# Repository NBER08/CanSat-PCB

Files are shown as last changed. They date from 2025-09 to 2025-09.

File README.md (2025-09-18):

# A custom PCB for the 2026 Hungarian CanSat competition
This is the the design me and my team are working on this year. This is the second year that we try ourselves at this competition. Dispite last years sub-optimal results we are determined to give our everything. Our goal this year is to get to the finals and launch our CanSat.

## General architecture

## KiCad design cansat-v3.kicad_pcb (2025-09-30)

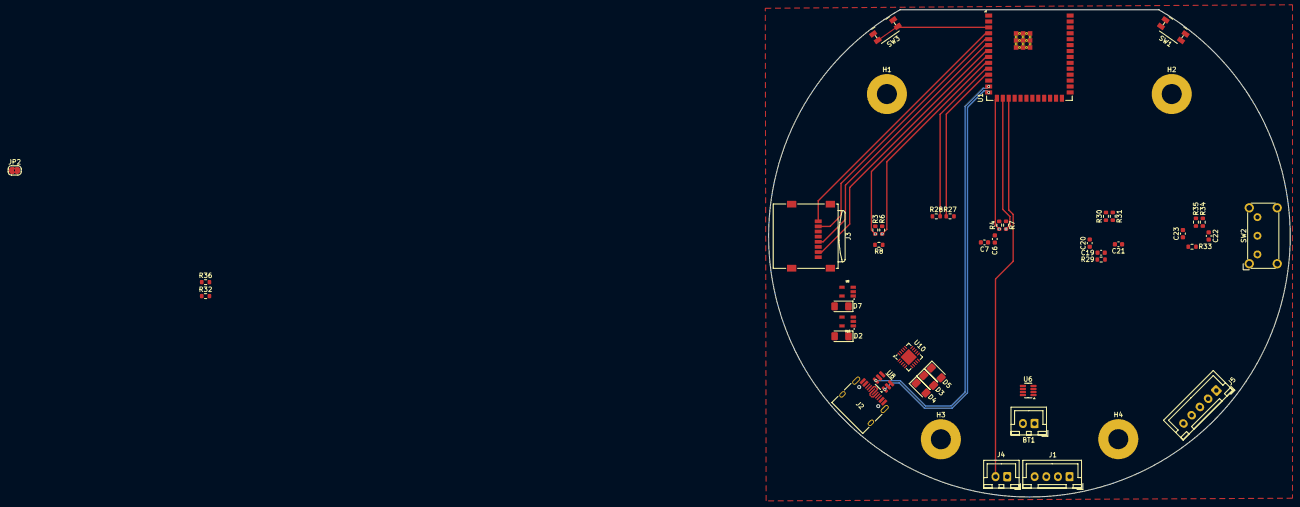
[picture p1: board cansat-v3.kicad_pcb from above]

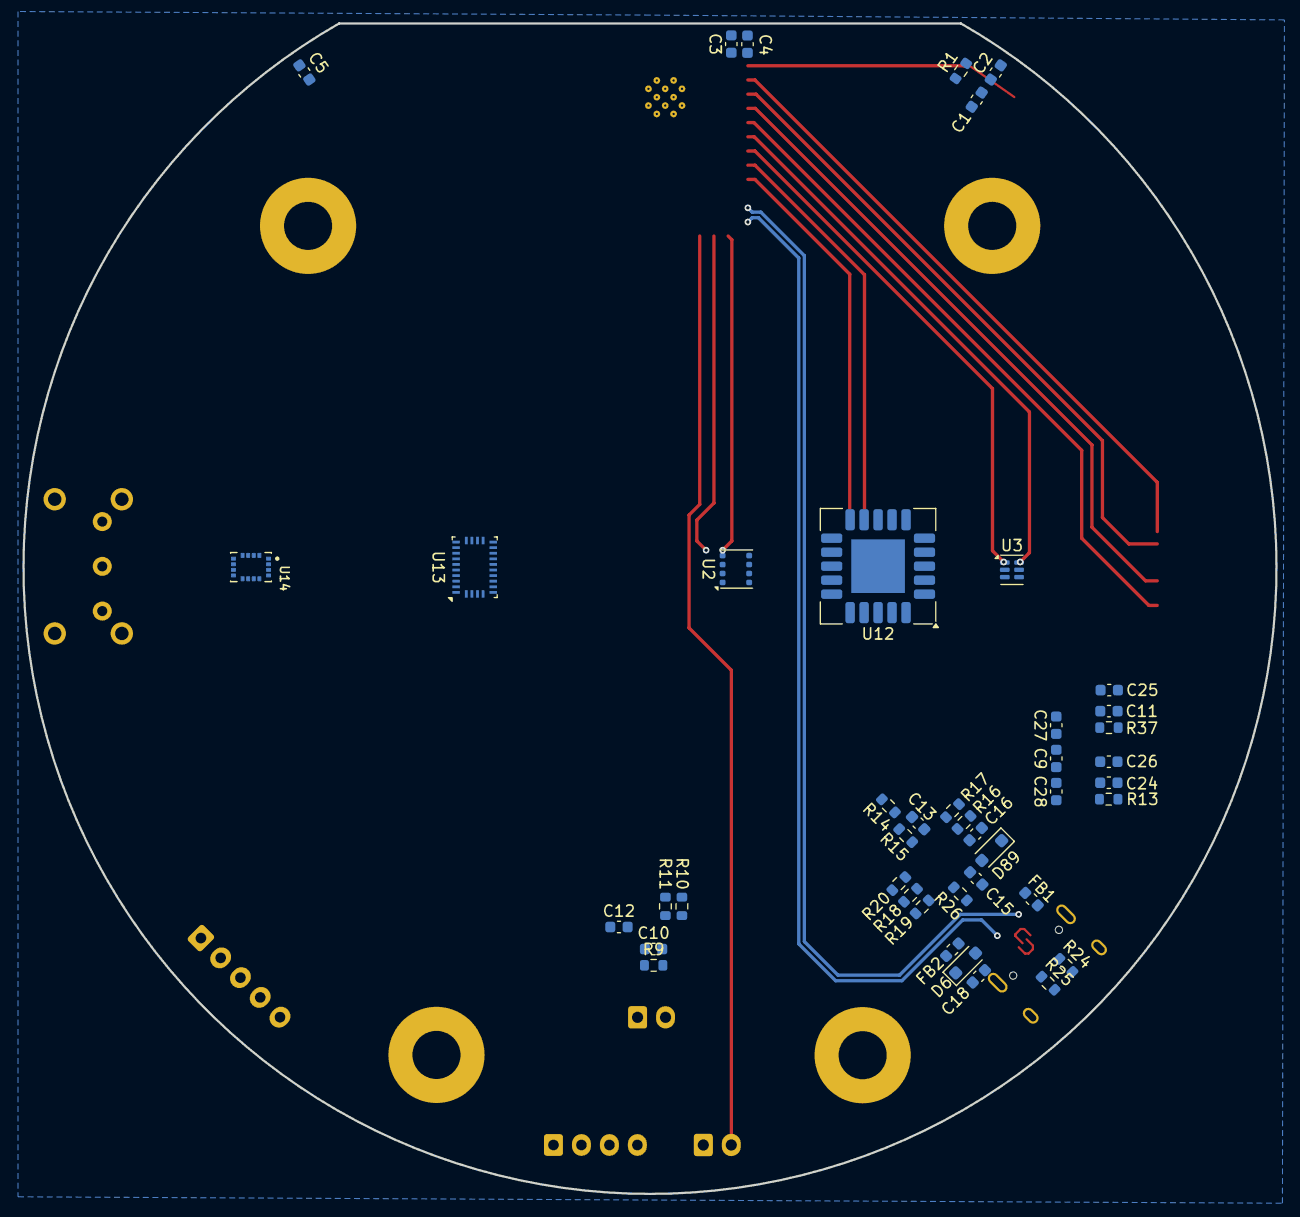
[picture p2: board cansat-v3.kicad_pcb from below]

Board: 4 copper layers, 112.0 x 104.6 mm, 90 parts (43 on the bottom side), 60 nets.

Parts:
BT1: Battery; JST_XH_B2B-XH-A_1x02_P2.50mm_Vertical
C1, C3, C5, C6, C7, C11, C12, C19, C22, C23, C24, C27, C28: 0.1u; C_0603_1608Metric
C2, C16: 10u; C_0603_1608Metric
C4: 22u; C_0603_1608Metric
C9: 470u; C_0603_1608Metric
C10, C20: 1u; C_0603_1608Metric
C13, C15: 4.7u; C_0603_1608Metric
C18: 100n; C_0603_1608Metric
C21: 0.12u; C_0603_1608Metric
C25, C26: 22n; C_0603_1608Metric
D2, D7: LED; LED_1206_3216Metric_Pad1.42x1.75mm_HandSolder
D3: Blue; LED_1206_3216Metric_Pad1.42x1.75mm_HandSolder
D4: Orange; LED_1206_3216Metric_Pad1.42x1.75mm_HandSolder
D5: Green; LED_1206_3216Metric_Pad1.42x1.75mm_HandSolder
D6: D_SOD-323_HandSoldering
D89: 1N5819; D_SOD-323_HandSoldering
FB1, FB2: LI0603G121R-10; L_0603_1608Metric
H1, H2, H3, H4: MountingHole_Pad; MountingHole_4.3mm_M4_Pad
J1: Conn_01x04_Socket; JST_XH_B4B-XH-A_1x04_P2.50mm_Vertical
J2: USB_C_Receptacle_USB2.0_16P; USB_C_Receptacle_HRO_TYPE-C-31-M-12
J3: Micro_SD_Card; microSD_HC_Wuerth_693072010801
J4: Conn_01x02_Socket; JST_XH_B2B-XH-A_1x02_P2.50mm_Vertical
J5: Conn_01x05_Socket; JST_XH_B5B-XH-A_1x05_P2.50mm_Vertical
JP2: SolderJumper_2_Bridged; SolderJumper-2_P1.3mm_Bridged2Bar_RoundedPad1.0x1.5mm
R1, R26, R27, R28, R29, R32, R36: 10k; R_0603_1608Metric
R3, R4, R6, R7, R8, R30, R31: 4.7k; R_0603_1608Metric
R9: 0.2; R_0603_1608Metric
R10, R11: 3.3k; R_0603_1608Metric
R13, R37: 66.5; R_0603_1608Metric
R14, R16: 2k; R_0603_1608Metric
R15: 1k; R_0603_1608Metric
R17: 2.4k; R_0603_1608Metric
R18: 68; R_0603_1608Metric
R19: 115; R_0603_1608Metric
R20: 100; R_0603_1608Metric
R24, R25: 5.1k; R_0603_1608Metric
R33: 3.3M; R_0603_1608Metric
R34, R35: 820; R_0603_1608Metric
SW1, SW3: SW_Push; Panasonic_EVQPUJ_EVQPUA
SW2: PWR; SW_E-Switch_EG1224_SPDT_Angled
U1: ESP32-S3-WROOM-2
U2: BME680; Bosch_LGA-8_3x3mm_P0.8mm_ClockwisePinNumbering
U3: TSL25911FN; AMS_TSL25911FN
U5: Analog PS; SOT94P279X129-5N
U6: INA219BxDCN; SOT-23-8
U8: SRV05-4; SOT-23-6_Handsoldering
U10: MCP73871; QFN-20-1EP_4x4mm_P0.5mm_EP2.5x2.5mm
U12: SCD40-D-R2; Sensirion_SCD4x-1EP_10.1x10.1mm_P1.25mm_EP4.8x4.8mm
U13: BNO055; LGA-28_5.2x3.8mm_P0.5mm
U14: AS7331-AQFM; PQFN50P365X260X119-16N
U15: Digital PS; SOT94P279X129-5N

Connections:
+3.3V: C3.1, C4.1, C6.1, C7.2, C12.2, C19.1, C22.1, C24.2, J1.1, J3.4 (VDD), J5.1, R1.1, R3.1, R4.2, R6.1, R7.2, R8.1, R10.1, R11.1, R13.1, R16.1, R27.1, R28.1, R29.1, R30.2, R31.2, R34.2, R35.2, U1.2 (3V3), U2.2 (CSB), U2.6 (VDDIO), U2.8 (VDD), U3.5 (VDD), U6.4 (VS), U10.4 (PROG2), U12.7 (VDD), U12.19 (VDD), U13.3 (VDD), U14.10 (VDDD), U15.5 (VOUT)
+5V: C16.1, D3.2 (A), D4.2 (A), D5.2 (A), FB1.2, U8.5 (VP), U10.2 (VPCC), U10.18 (IN), U10.19 (IN)
+BATT: BT1.1 (+), C10.1, C13.1, R9.1, SW2.1 (A), U6.1 (IN+), U10.14 (V_{BAT}), U10.15 (V_{BAT}), U10.16 (V_{BAT_SENSE})
/RST: C1.2, C2.1, R1.2, SW3.2, U1.3 (EN)
AS7331_SCL: R35.1, U1.33 (MTDO/IO40), U14.13 (SCL)
AS7331_SDA: R34.1, U1.34 (MTDI/IO41), U14.12 (SDA)
BME680_SCL: R4.1, U1.15 (IO3), U2.4 (SCK)
BME680_SDA: R7.1, U1.16 (IO46), U2.3 (SDI)
BNO055_RST: U1.23 (IO21), U13.11 (~RESET)
BNO055_SCL: R30.1, U1.31 (IO38), U13.19 (COM1)
BNO055_SDA: R31.1, U1.26 (IO45), U13.20 (COM0)
COMPASS_SCL: J4.2, U1.17 (IO9)
COMPASS_SDA: J4.1, U1.18 (IO10)
Earth: C18.1, D6.2 (A2), FB2.2, J2.A1 (GND), J2.A12 (GND), J2.B1 (GND), J2.B12 (GND), J2.S1 (SHIELD)
GND: BT1.2 (-), C1.1, C2.2, C3.2, C4.2, C5.1, C6.2, C7.1, C10.2, C11.1, C12.1, C13.2, C15.2, C16.2, C18.2, C19.2, C20.1, C21.1, C22.2, C24.1, C25.1, C26.1, C27.2, C28.1, D2.1 (K), D6.1 (A1), D7.1 (K), FB2.1, H1.1, H2.1, H3.1, H4.1, J1.2, J3.3 (CMD), J3.6 (VSS), J5.4, JP2.1 (A), R9.2, R14.2, R15.2, R17.2, R24.2, R25.2, R26.2, R32.2, R36.2, SW1.2, SW3.1, U1.1 (GND), U1.40 (GND), U1.41 (GND), U2.1 (GND), U2.5 (SDO), U2.7 (GND), U3.3 (GND), U5.2 (GND), U6.2 (IN-), U6.3 (GND), U6.7 (A0), U6.8 (A1), U8.2 (VN), U10.3 (SEL), U10.9 (~TE), U10.10 (V_{SS}), U10.11 (V_{SS}), U10.21 (V_{SS}), U12.6 (GND), U12.20 (GND), U12.21 (GND), U13.2 (GND), U13.5 (PS1), U13.6 (PS0), U13.17 (COM3), U13.18 (COM2), U13.25 (GNDIO), U14.11 (VSSD), U15.2 (GND)
GPS_RX: J1.3, U1.21 (IO13)
GPS_TX: J1.4, U1.22 (IO14)
INA219_SCL: R11.2, U1.20 (IO12), U6.5 (SCL)
INA219_SDA: R10.2, U1.19 (IO11), U6.6 (SDA)
LoRa_RST: J5.5, U1.32 (MTCK/IO39)
LoRa_RX: J5.3, U1.36 (RXD0/IO44)
LoRa_TX: J5.2, U1.37 (TXD0/IO43)
unnamed: D2.2 (A), R13.2
unnamed: D3.1 (K), R18.1
unnamed: D4.1 (K), R19.1
unnamed: D5.1 (K), R20.1
unnamed: D7.2 (A), R37.2
unnamed: C15.1, D89.2 (A), U10.1 (OUT), U10.20 (OUT)
unnamed: C9.1, C9.2, C27.1, C28.2, D89.1 (K), U5.1 (VIN), U15.1 (VIN)
unnamed: J2.A5 (CC1), R24.1
unnamed: J2.B5 (CC2), R25.1
unnamed: C5.2, SW1.1, U1.27 (IO0)
unnamed: R8.2, U3.2 (INT)
unnamed: C25.2, U5.4 (BP)
unnamed: R16.2, R17.1, U10.17 (CE)
unnamed: R14.1, U10.13 (PROG1)
unnamed: R15.1, U10.12 (PROG3)
unnamed: R20.2, U10.8 (STAT1/~LBO)
unnamed: R18.2, U10.7 (STAT2)
unnamed: R26.1, U10.5 (THERM)
unnamed: R19.2, U10.6 (~PG)
unnamed: C20.2, U13.9 (CAP)
unnamed: C21.2, U13.28 (VDDIO)
unnamed: R29.2, U13.4 (~BOOT_LOAD_PIN)
unnamed: R33.1, U14.4 (REXT)
unnamed: C26.2, U15.4 (BP)
PWR_EN: R32.1, R36.1, SW2.2 (B), U5.3 (EN), U15.3 (EN)
SCD40_SCL: R28.2, U1.10 (IO17), U12.9 (SCL)
SCD40_SDA: R27.2, U1.11 (IO18), U12.10 (SDA)
SD_CLK: J3.5 (CLK), U1.6 (IO6)
SD_CS: J3.1 (DAT2), U1.4 (IO4)
SD_MISO: J3.7 (DAT0), U1.7 (IO7)
SD_MOSI: J3.2 (DAT3/CD), U1.5 (IO5)
TSL2591_SCL: R6.2, U1.9 (IO16), U3.1 (SCL)
TSL2591_SDA: R3.2, U1.8 (IO15), U3.6 (SDA)
USB_D+: J2.A6 (D+), J2.B6 (D+), U1.14 (USB_D+/IO20), U8.1 (IO1)
USB_D-: J2.A7 (D-), J2.B7 (D-), U1.13 (USB_D-/IO19), U8.6 (IO4)
VBUS: FB1.1, J2.A4 (VBUS), J2.A9 (VBUS), J2.B4 (VBUS), J2.B9 (VBUS)
VDDA: C11.2, C23.1, R37.1, U5.5 (VOUT), U14.3 (VDDA)
VSSA: C23.2, JP2.2 (B), R33.2, U14.1 (VSSA), U14.2 (VSSA), U14.5 (VSSA), U14.6 (VSSA), U14.7 (A1), U14.14 (A0), U14.15 (VSSA), U14.16 (VSSA)

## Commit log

2025-09-25 new desktop first commit
    [cansat-v3.kicad_sch]
2025-09-25 autopush test
    [cansat-v3.kicad_sch]
2025-09-26 Sensor development
    [cansat-v3.kicad_sch]
2025-09-27 Power subsystem finished, Sensors continued
    [cansat-v3.kicad_sch]
2025-09-28 Started layout
    [cansat-v3.kicad_pcb, cansat-v3.kicad_sch]
2025-09-30 Component placement finished, started routing
    [cansat-v3.kicad_pcb, cansat-v3.kicad_sch]
